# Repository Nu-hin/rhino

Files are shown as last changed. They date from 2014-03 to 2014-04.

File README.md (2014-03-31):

# Rhino

Rhino

## Description

Rhino is a robot based on AVR ATmega microcontroller.

Here's a list of its features:

* it runs on [AVR ATmega8](http://www.atmel.com/devices/atmega8.aspx "ATmega8") microcontroller;
* it moves around on cool tank tracks;
* it has 3 different sensors: ultrasonic distance sensor, lightning sensor, 3-axis accelerometer (as a removable module);
* it has a Bluetooth serial module (removable);
* it has 4 bright white LEDs to light its way;
* it has three general-purpose LED indicators (red, green, blue);
* it can produce an irritating sound;
* it has a potentiometer (to adjust continuous parameters) and a general-purpose button (to adjust discrete ones);
* it runs on 4 AA accumulators.

This repository contains PCB and firmware for Rhino. PCB files are prepared with [KiCAD](http://www.kicad-pcb.org/ "KiCAD").

Fork the repository and make your own Rhino!

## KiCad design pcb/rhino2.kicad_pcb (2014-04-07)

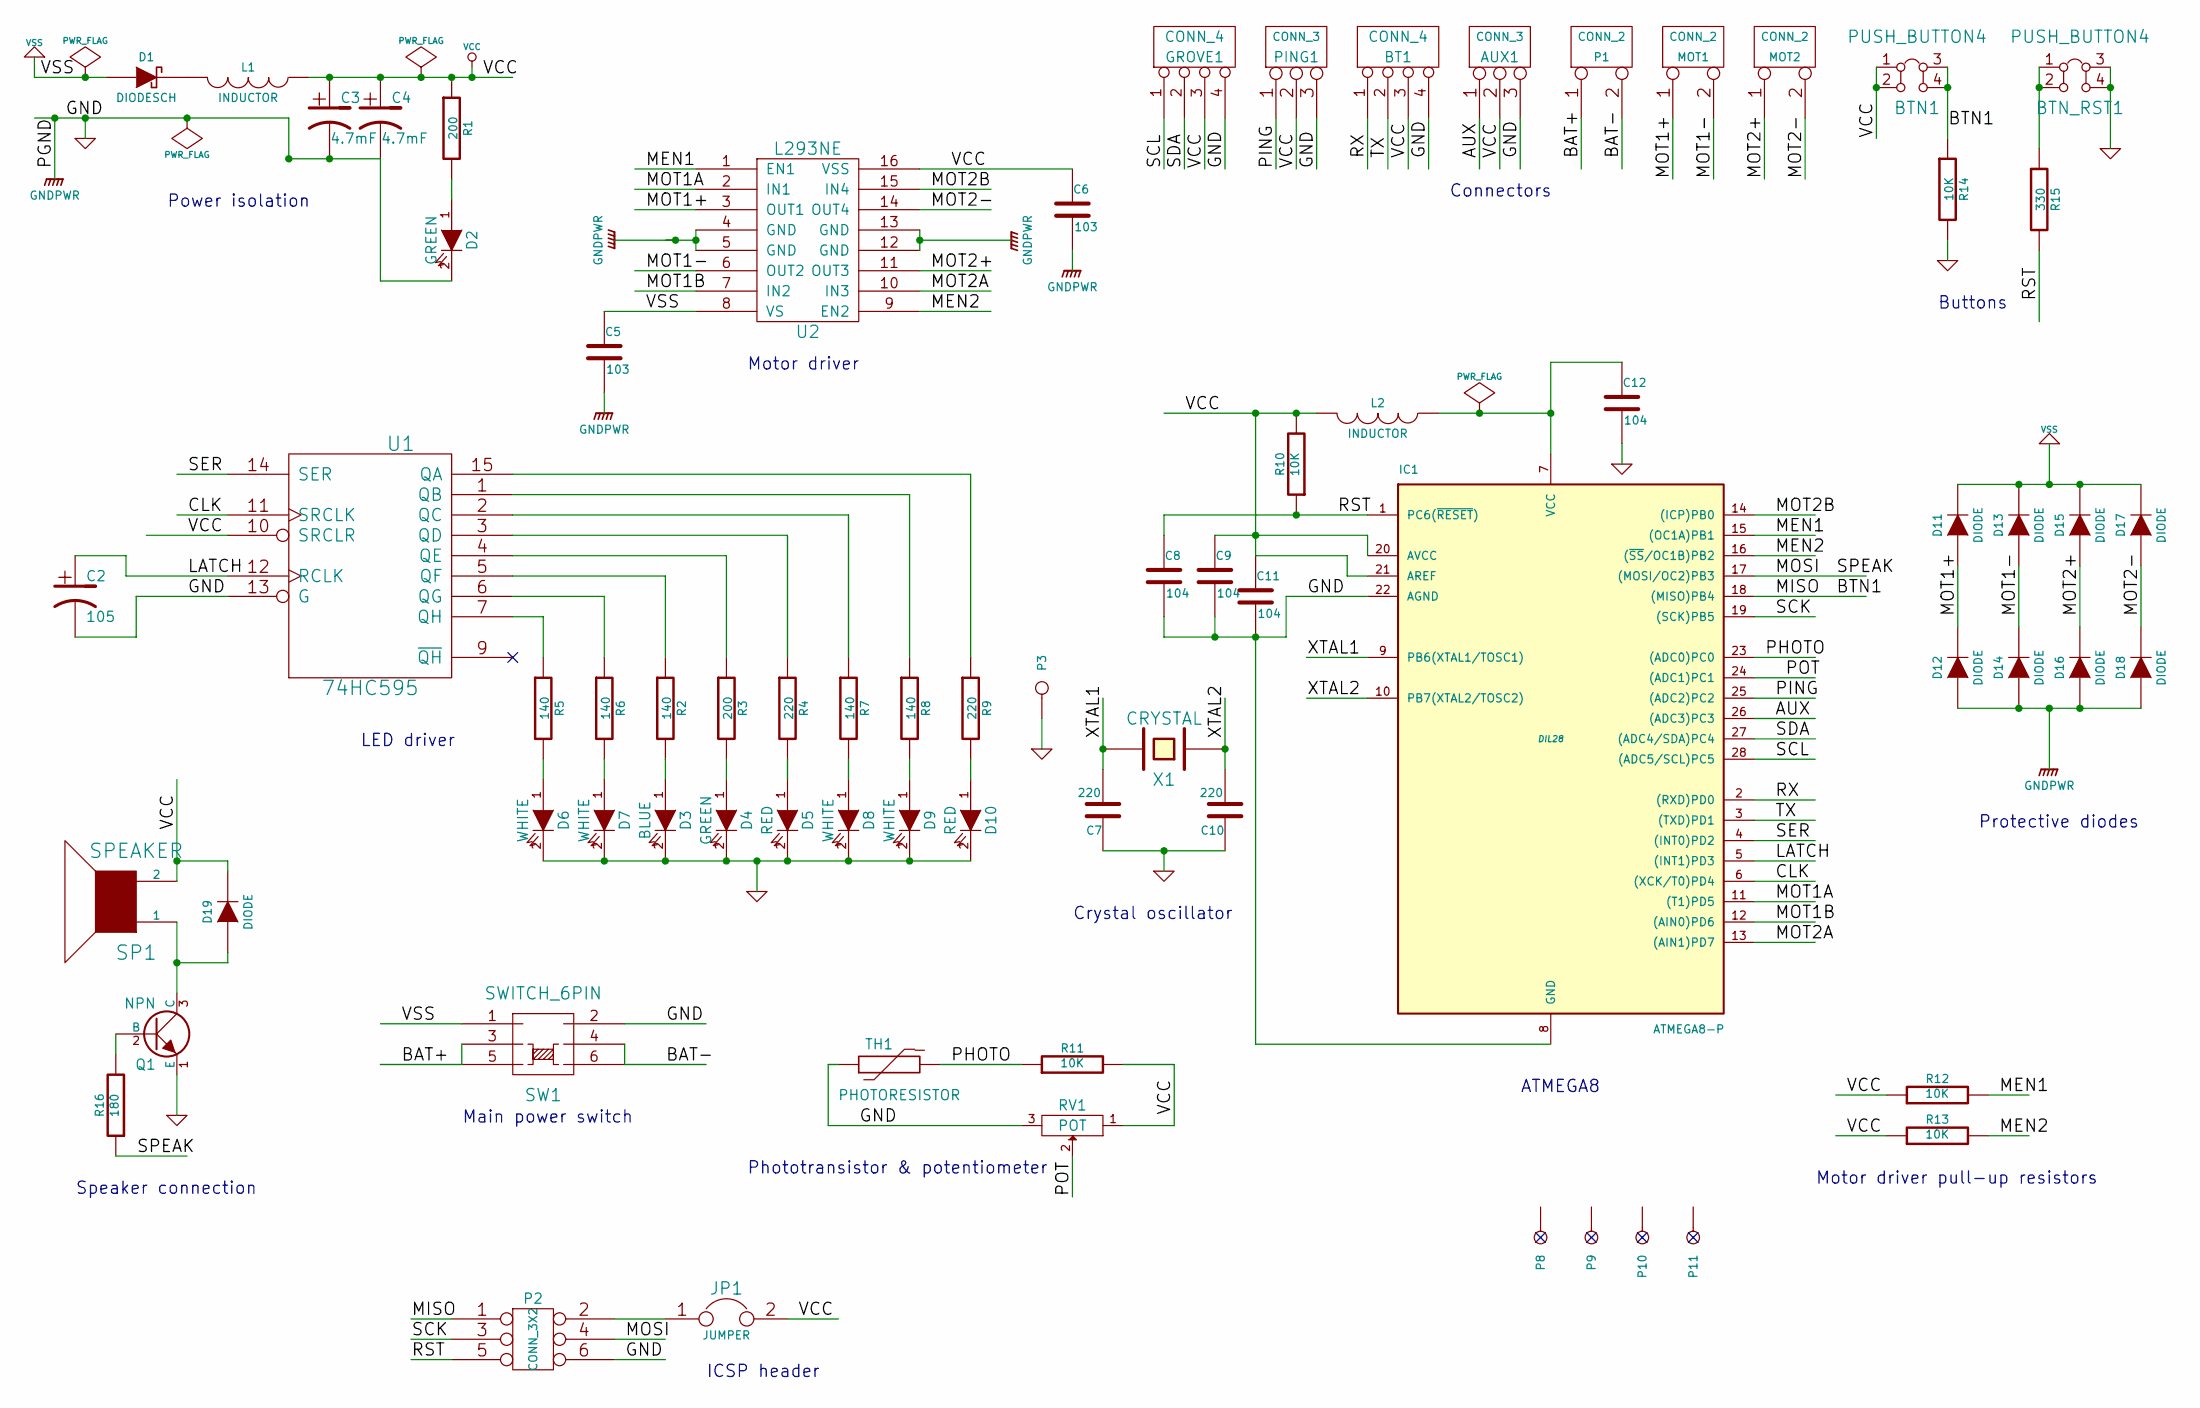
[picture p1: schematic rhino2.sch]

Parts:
AUX1: CONN_3
BT1: CONN_4
BTN1: PUSH_BUTTON4
BTN_RST1: PUSH_BUTTON4
C2: 105
C3, C4: 4.7mF
C5, C6: 103
C7, C10: 220
C8, C9, C11, C12: 104
D1: DIODESCH
D2, D4: GREEN
D3: BLUE
D5, D10: RED
D6, D7, D8, D9: WHITE
D11, D12, D13, D14, D15, D16, D17, D18, D19: DIODE
GROVE1: CONN_4
IC1: ATMEGA8-P; DIL28
JP1: JUMPER
L1, L2: INDUCTOR
MOT1, MOT2: CONN_2
P1: CONN_2
P2: CONN_3X2
P3, P8, P9, P10, P11: CONN_1
PING1: CONN_3
Q1: NPN
R1, R3: 200
R2, R5, R6, R7, R8: 140
R4, R9: 220
R10, R11, R12, R13, R14: 10K
R15: 330
R16: 180
RV1: POT
SP1: SPEAKER
SW1: SWITCH_6PIN
TH1: PHOTORESISTOR
U1: 74HC595
U2: L293NE
X1: CRYSTAL

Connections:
/AUX: AUX1.1, IC1.26 ((ADC3)PC3)
/BAT+: P1.1, SW1.3, SW1.5
/BAT-: P1.2 (PM), SW1.4, SW1.6
/BTN1: BTN1.3, BTN1.4, IC1.18 ((MISO)PB4), P2.1, R14.1
/CLK: IC1.6 ((XCK/T0)PD4), U1.11 (SRCLK)
/LATCH: C2.1, IC1.5 ((INT1)PD3), U1.12 (RCLK)
/MEN1: IC1.15 ((OC1A)PB1), R12.2, U2.1 (EN1)
/MEN2: IC1.16 ((~SS~/OC1B)PB2), R13.2, U2.9 (EN2)
/MOSI: IC1.17 ((MOSI/OC2)PB3), P2.4, R16.1
/MOT1+: D11.1 (A), D12.2 (K), MOT1.1, U2.3 (OUT1)
/MOT1-: D13.1 (A), D14.2 (K), MOT1.2 (PM), U2.6 (OUT2)
/MOT1A: IC1.11 ((T1)PD5), U2.2 (IN1)
/MOT1B: IC1.12 ((AIN0)PD6), U2.7 (IN2)
/MOT2+: D15.1 (A), D16.2 (K), MOT2.1, U2.11 (OUT3)
/MOT2-: D17.1 (A), D18.2 (K), MOT2.2 (PM), U2.14 (OUT4)
/MOT2A: IC1.13 ((AIN1)PD7), U2.10 (IN3)
/MOT2B: IC1.14 ((ICP)PB0), U2.15 (IN4)
/PHOTO: IC1.23 ((ADC0)PC0), R11.1, TH1.2
/PING: IC1.25 ((ADC2)PC2), PING1.1
/POT: IC1.24 ((ADC1)PC1), RV1.2
/RST: C8.1, IC1.1 (PC6(~RESET~)), P2.5, R10.1, R15.2
/RX: BT1.1, IC1.2 ((RXD)PD0)
/SCK: IC1.19 ((SCK)PB5), P2.3
/SCL: GROVE1.1, IC1.28 ((ADC5/SCL)PC5)
/SDA: GROVE1.2, IC1.27 ((ADC4/SDA)PC4)
/SER: IC1.4 ((INT0)PD2), U1.14 (SER)
/TX: BT1.2, IC1.3 ((TXD)PD1)
/XTAL1: C7.2, IC1.9 (PB6(XTAL1/TOSC1)), X1.2
/XTAL2: C10.2, IC1.10 (PB7(XTAL2/TOSC2)), X1.1
GND: AUX1.3, BT1.4, BTN_RST1.3, BTN_RST1.4, C2.2, C3.2, C4.2, C5.2, C6.2, C7.1, C8.2, C9.2, C10.1, C11.2, C12.2, D2.2 (K), D3.2 (K), D4.2 (K), D5.2 (K), D6.2 (K), D7.2 (K), D8.2 (K), D9.2 (K), D10.2 (K), D12.1 (A), D14.1 (A), D16.1 (A), D18.1 (A), GROVE1.4, IC1.8 (GND), IC1.22 (AGND), P2.6, P3.1, PING1.3, Q1.1 (E), R14.2, RV1.3, SW1.2, TH1.1, U1.8 (GND), U1.13 (G), U2.4 (GND), U2.5 (GND), U2.12 (GND), U2.13 (GND)
unnamed: JP1.1, P2.2
unnamed: D2.1 (A), R1.2
unnamed: R9.1, U1.15 (QA)
unnamed: D10.1 (A), R9.2
unnamed: D19.1 (A), Q1.3 (C), SP1.1
unnamed: Q1.2 (B), R16.2
unnamed: C12.1, IC1.7 (VCC), L2.1
unnamed: D3.1 (A), R2.2
unnamed: D4.1 (A), R3.2
unnamed: D5.1 (A), R4.2
unnamed: D6.1 (A), R5.2
unnamed: D7.1 (A), R6.2
unnamed: D8.1 (A), R7.2
unnamed: R3.1, U1.4 (QE)
unnamed: D9.1 (A), R8.2
unnamed: R5.1, U1.7 (QH)
unnamed: R6.1, U1.6 (QG)
unnamed: R2.1, U1.5 (QF)
unnamed: R4.1, U1.3 (QD)
unnamed: R7.1, U1.2 (QC)
unnamed: R8.1, U1.1 (QB)
unnamed: D1.2 (K), L1.2
unnamed: BTN_RST1.1, BTN_RST1.2, R15.1
VCC: AUX1.2 (PM), BT1.3, BTN1.1, BTN1.2, C3.1, C4.1, C6.1, C9.1, C11.1, D19.2 (K), GROVE1.3, IC1.20 (AVCC), IC1.21 (AREF), JP1.2, L1.1, L2.2, PING1.2 (PM), R1.1, R10.2, R11.2, R12.1, R13.1, RV1.1, SP1.2, U1.10 (SRCLR), U1.16 (VCC), U2.16 (VSS)
VSS: C5.1, D1.1 (A), D11.2 (K), D13.2 (K), D15.2 (K), D17.2 (K), SW1.1, U2.8 (VS)

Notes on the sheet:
Speaker connection
Main power switch
LED driver
Power isolation
Motor driver
ICSP header
Crystal oscillator
ATMEGA8
Phototransistor & potentiometer
Motor driver pull-up resistors
Buttons
Connectors
Protective diodes

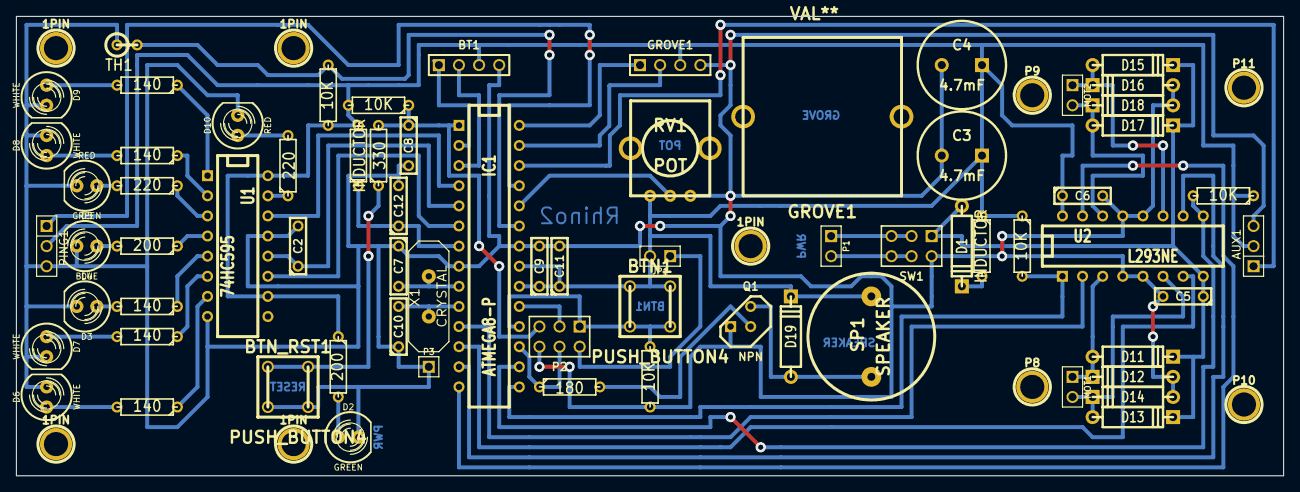
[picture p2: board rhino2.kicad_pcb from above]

Board: 2 copper layers, 160.0 x 58.0 mm, 79 parts (0 on the bottom side), 55 nets.

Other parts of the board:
1PIN, 1PIN#2, 1PIN#3, 1PIN#4, 1PIN#5: P***; 1pin
GROVE1#2: VAL**; GROVE1

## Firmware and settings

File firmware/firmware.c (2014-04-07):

#include "common.h"
#include <avr/io.h>
#include <util/delay.h>
#include "shift.h"
#include "sound.h"
#include "adc.h"
#include "ping.h"
#include "motor.h"
#include "usart.h"

void sendReport()
{
	int pot = getResult(ADC1);
	int light = getResult(ADC0);
	unsigned long cm = getDistanceCm();

	uart_putc('R');
	uart_putc(pot);
	uart_putc(pot>>8);


	uart_putc(light);
	uart_putc(light>>8);

	uart_putc(cm);
	uart_putc(cm>>8);
	uart_putc(cm>>16);
	uart_putc(cm>>24);
	uart_putc(0);

}



int main(void)
{
	initShift();
	initSound();
	initMotors();
	initAdc();

	setByte(0xFF);

	uart_init(38400);
	_delay_ms(1000);
	uart_puts("\r\n+STWMOD=0\r\n");
	uart_puts("\r\n+STNA=Rhino2 Drone\r\n");
	uart_puts("\r\n+STAUTO=0\r\n");
	uart_puts("\r\n+STOAUT=1\r\n");
	uart_puts("\r\n +STPIN=0000\r\n");
	_delay_ms(2000);
	uart_puts("\r\n+INQ=1\r\n");
	_delay_ms(2000);


	for(int i=0; i<6; i++)
	{
		beep(100);
		_delay_ms(100);
	}

	setByte(0);

	enableMotors(1,1);
	setMotorsAB(0,0,0,0);

	while(1)
	{
		int z= uart_getc();
		if(z=='Q')
		{
			uart_getc();
			sendReport();
		}

		if(z=='C')
		{
			int lmotor;
			int rmotor;
			setByte(uart_getc());
			z=uart_getc();
			lmotor = z << 8;
			z=uart_getc();
			lmotor |= z;
			z=uart_getc();
			rmotor = z <<8;
			z=uart_getc();
			rmotor |= z;
			z=uart_getc();
			if(z)
			{
				soundOn();
			}
			else
			{
				soundOff();
			}
			uart_getc();

			setMotors(lmotor,rmotor);
		}
	}
}

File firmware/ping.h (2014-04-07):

#ifndef PING_H_
#define PING_H_
#include "common.h"
#include <avr/io.h>
#include <util/delay.h>


#define USTOCM(x) ( x/29/2 )
#define PINGP PORTC
#define PINGD DDRC
#define PINGPIN (1<<PC2)
#define PINGIN PINC



unsigned long pulseIn(unsigned long timeout);

unsigned long getDistanceCm();




#endif /* PING_H_ */

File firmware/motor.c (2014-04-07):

#include "motor.h"

void initMotors()
{
	MOT1AD |= MOT1A;
	MOT1BD |= MOT1B;
	MOT2AD |= MOT2A;
	MOT2BD |= MOT2B;
	MOT1END |= MOT1EN;
	MOT2END |= MOT2EN;
}

void setMotorsAB(unsigned char m1a, unsigned char m1b,unsigned char m2a, unsigned char m2b)
{
	if(m1a)
	{
		MOT1AP |= MOT1A;
	}
	else
	{
		MOT1AP &= ~MOT1A;
	}

	if(m1b)
	{
		MOT1BP |= MOT1B;
	}
	else
	{
		MOT1BP &= ~MOT1B;
	}

	if(m2a)
	{
		MOT2AP |= MOT2A;
	}
	else
	{
		MOT2AP &= ~MOT2A;
	}

	if(m2b)
	{
		MOT2BP |= MOT2B;
	}
	else
	{
		MOT2BP &= ~MOT2B;
	}
}

void enableMotors(unsigned char m1, unsigned char m2)
{
	if(m1)
	{
		MOT1ENP |= MOT1EN;
	}
	else
	{
		MOT1ENP &= ~MOT1EN;
	}

	if(m2)
	{
		MOT2ENP |= MOT2EN;
	}
	else
	{
		MOT2ENP &= ~MOT2EN;
	}

}

void forward()
{
	enableMotors(0,0);
	setMotorsAB(1,0,1,0);
	enableMotors(1,1);
}


void backward()
{
	enableMotors(0,0);
	setMotorsAB(0,1,0,1);
	enableMotors(1,1);
}


void left()
{
	enableMotors(0,0);
	setMotorsAB(0,1,1,0);
	enableMotors(1,1);
}
void right()
{
	enableMotors(0,0);
	setMotorsAB(1,0,0,1);
	enableMotors(1,1);
}


void stop()
{
	setMotorsAB(1,1,1,1);
	enableMotors(0,0);
}

void setMotors(int m1, int m2)
{
	setMotorsAB(m1 > 0 ? 1 : 0, m1 < 0 ? 1 : 0, m2 > 0 ? 1 : 0, m2 < 0 ? 1 : 0 );
}

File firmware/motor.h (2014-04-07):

#ifndef MOTORH_H_
#define MOTORH_H_
#include "common.h"
#include <avr/io.h>

#define MOT1AD DDRD
#define MOT1BD DDRD
#define MOT2AD DDRD
#define MOT2BD DDRB
#define MOT1END DDRB
#define MOT2END DDRB


#define MOT1AP PORTD
#define MOT1BP PORTD
#define MOT2AP PORTD
#define MOT2BP PORTB
#define MOT1ENP PORTB
#define MOT2ENP PORTB

#define MOT1B (1<<PD5)
#define MOT1A (1<<PD6)
#define MOT2A (1<<PD7)
#define MOT2B (1<<PB0)
#define MOT1EN (1<<PB1)
#define MOT2EN (1<<PB2)


void initMotors();


void setMotorsAB(unsigned char m1a, unsigned char m1b,unsigned char m2a, unsigned char m2b);
void setMotors(int m1, int m2);

void enableMotors(unsigned char m1, unsigned char m2);

void forward();
void backward();
void left();
void right();
void stop();


#endif /* MOTORH_H_ */
